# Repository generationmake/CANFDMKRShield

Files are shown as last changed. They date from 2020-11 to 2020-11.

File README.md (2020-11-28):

# CANFDMKRShield
Shield with CAN FD Controller MCP2517 for Arduino MKR

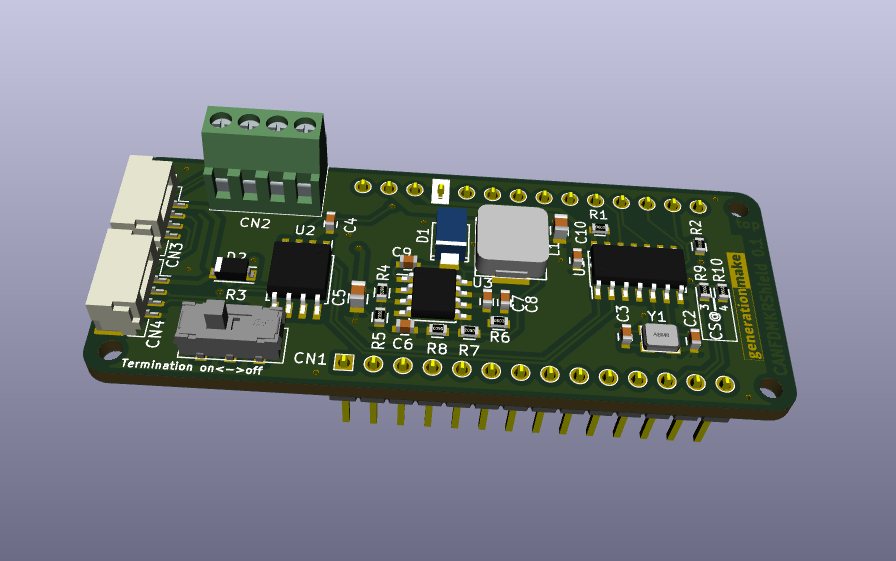
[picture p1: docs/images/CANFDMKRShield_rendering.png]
CANFDMKRShield rendering


## pin usage

### Arduino MKR connector CN1

| **Pin** | **Pin Name** | **Signal** | **Description** |
|:---:|:---:|:---:|:---:|
| 1 | AREF | | |
| 2 | DAC0/A0 | | |
| 3 | A1 | | |
| 4 | A2 | | |
| 5 | A3 | | |
| 6 | A4 | | |
| 7 | A5 | | |
| 8 | A6 | | |
| 9 | 0 | | |
| 10 | 1 | | |
| 11 | 2 | | |
| 12 | 3 | MCP2517_CS1 | option 1 for chip select for MCP2517 |
| 13 | 4 | MCP2517_CS2 | option 2 for chip select for MCP2517 |
| 14 | 5 | | |
| 15 | 6 | | |
| 16 | 7 | MCP2517_INT | interrupt from MCP2517 |
| 17 | 8/MOSI | SPI_MOSI | SPI to MCP2517 |
| 18 | 9/SCK | SPI_SCK | SPI to MCP2517 |
| 19 | 10/MISO | SPI_MISO | SPI to MCP2517 |
| 20 | 11/SDA | | |
| 21 | 12/SCL | | |
| 22 | 13/RX | | |
| 23 | 14/TX | | |
| 24 | RESET | | |
| 25 | GND | GND | |
| 26 | VCC | 3V3-rail | supply voltage for board |
| 27 | VIN | +5V | 5V supply output from CAN connector  |
| 28 | 5V0 | | |

### CAN connector CN2

compatible to Sparkfun Qwiic. JST SH 1mm 4-pin.

| **Pin** | **Signal** | **Description** |
|:---:|:---:|:---:|
| 1 | GND | |
| 2 | CAN_L | |
| 3 | CAN_H | |
| 4 | VCC | input to Arduino, up to 24 V |

### UAVCAN dronecode connector CN3 and CN4

compatible to UAVCAN dronecode. JST GH 1.25mm 4-pin.

| **Pin** | **Signal** | **Description** |
|:---:|:---:|:---:|
| 1 | CANVCC | up to 5.5 V |
| 2 | CAN_H | |
| 3 | CAN_L | |
| 4 | GND | |

CANVCC can be connected to Arduino via diode D2 as desribed in the dronecode spec. The direction of the diode defines wether current is sourced from the connector or supplied into the UAVCAN system. If no connection is desired just leave D2 unpopulated.

## PCB

### Top

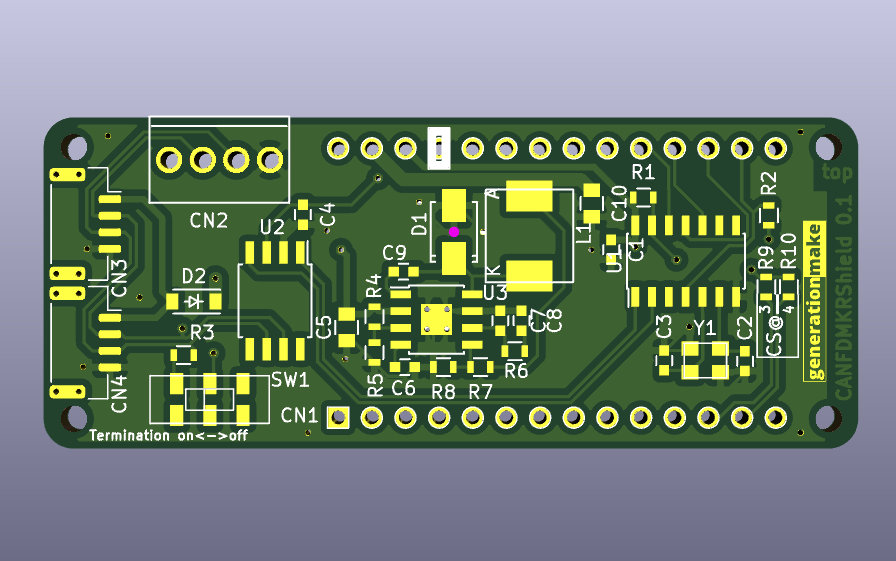
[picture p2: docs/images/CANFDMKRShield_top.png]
CANFDMKRShield PCB top


### Bottom

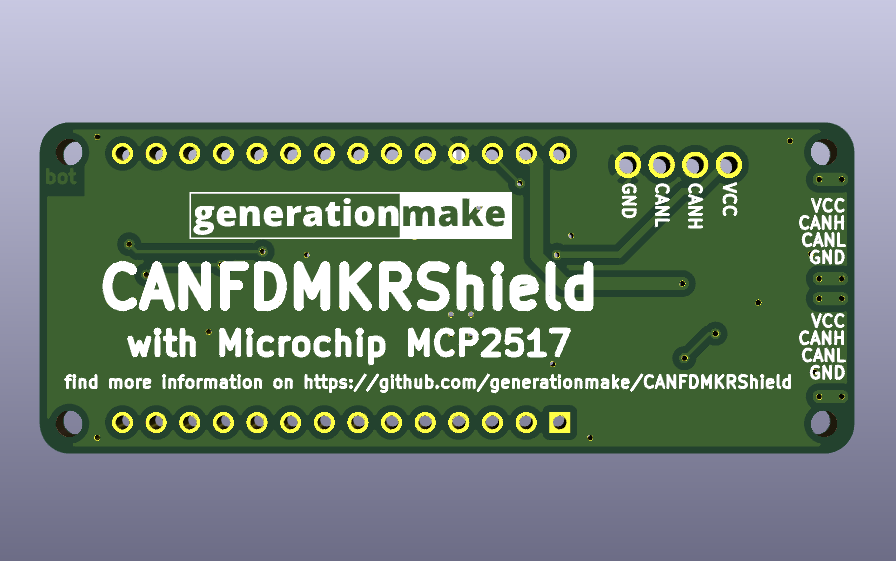
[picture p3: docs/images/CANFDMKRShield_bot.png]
CANFDMKRShield PCB bot


## Resources

### Datasheets

 * http://ww1.microchip.com/downloads/en/DeviceDoc/MCP2517FD-External-CAN-FD-Controller-with-SPI-Interface-20005688B.pdf
 
### Arduino Libraries

 * tbd

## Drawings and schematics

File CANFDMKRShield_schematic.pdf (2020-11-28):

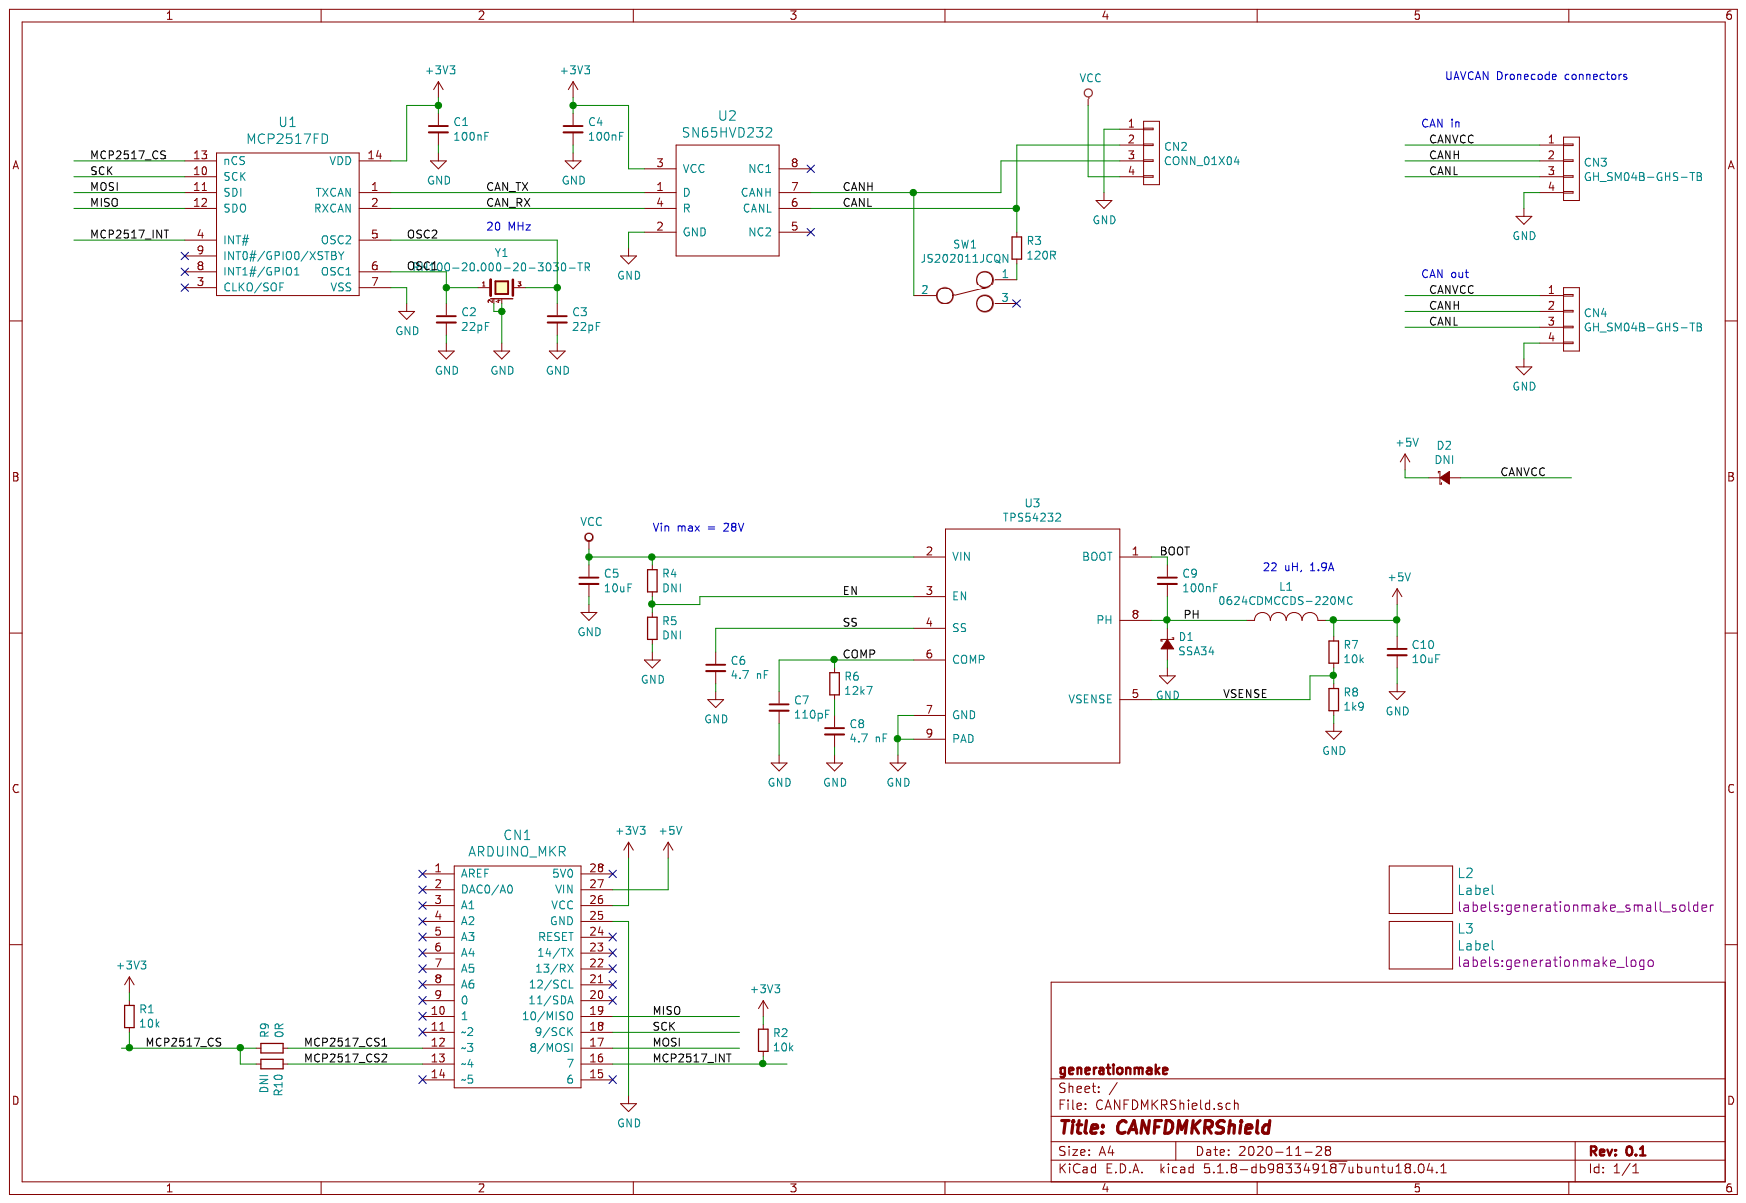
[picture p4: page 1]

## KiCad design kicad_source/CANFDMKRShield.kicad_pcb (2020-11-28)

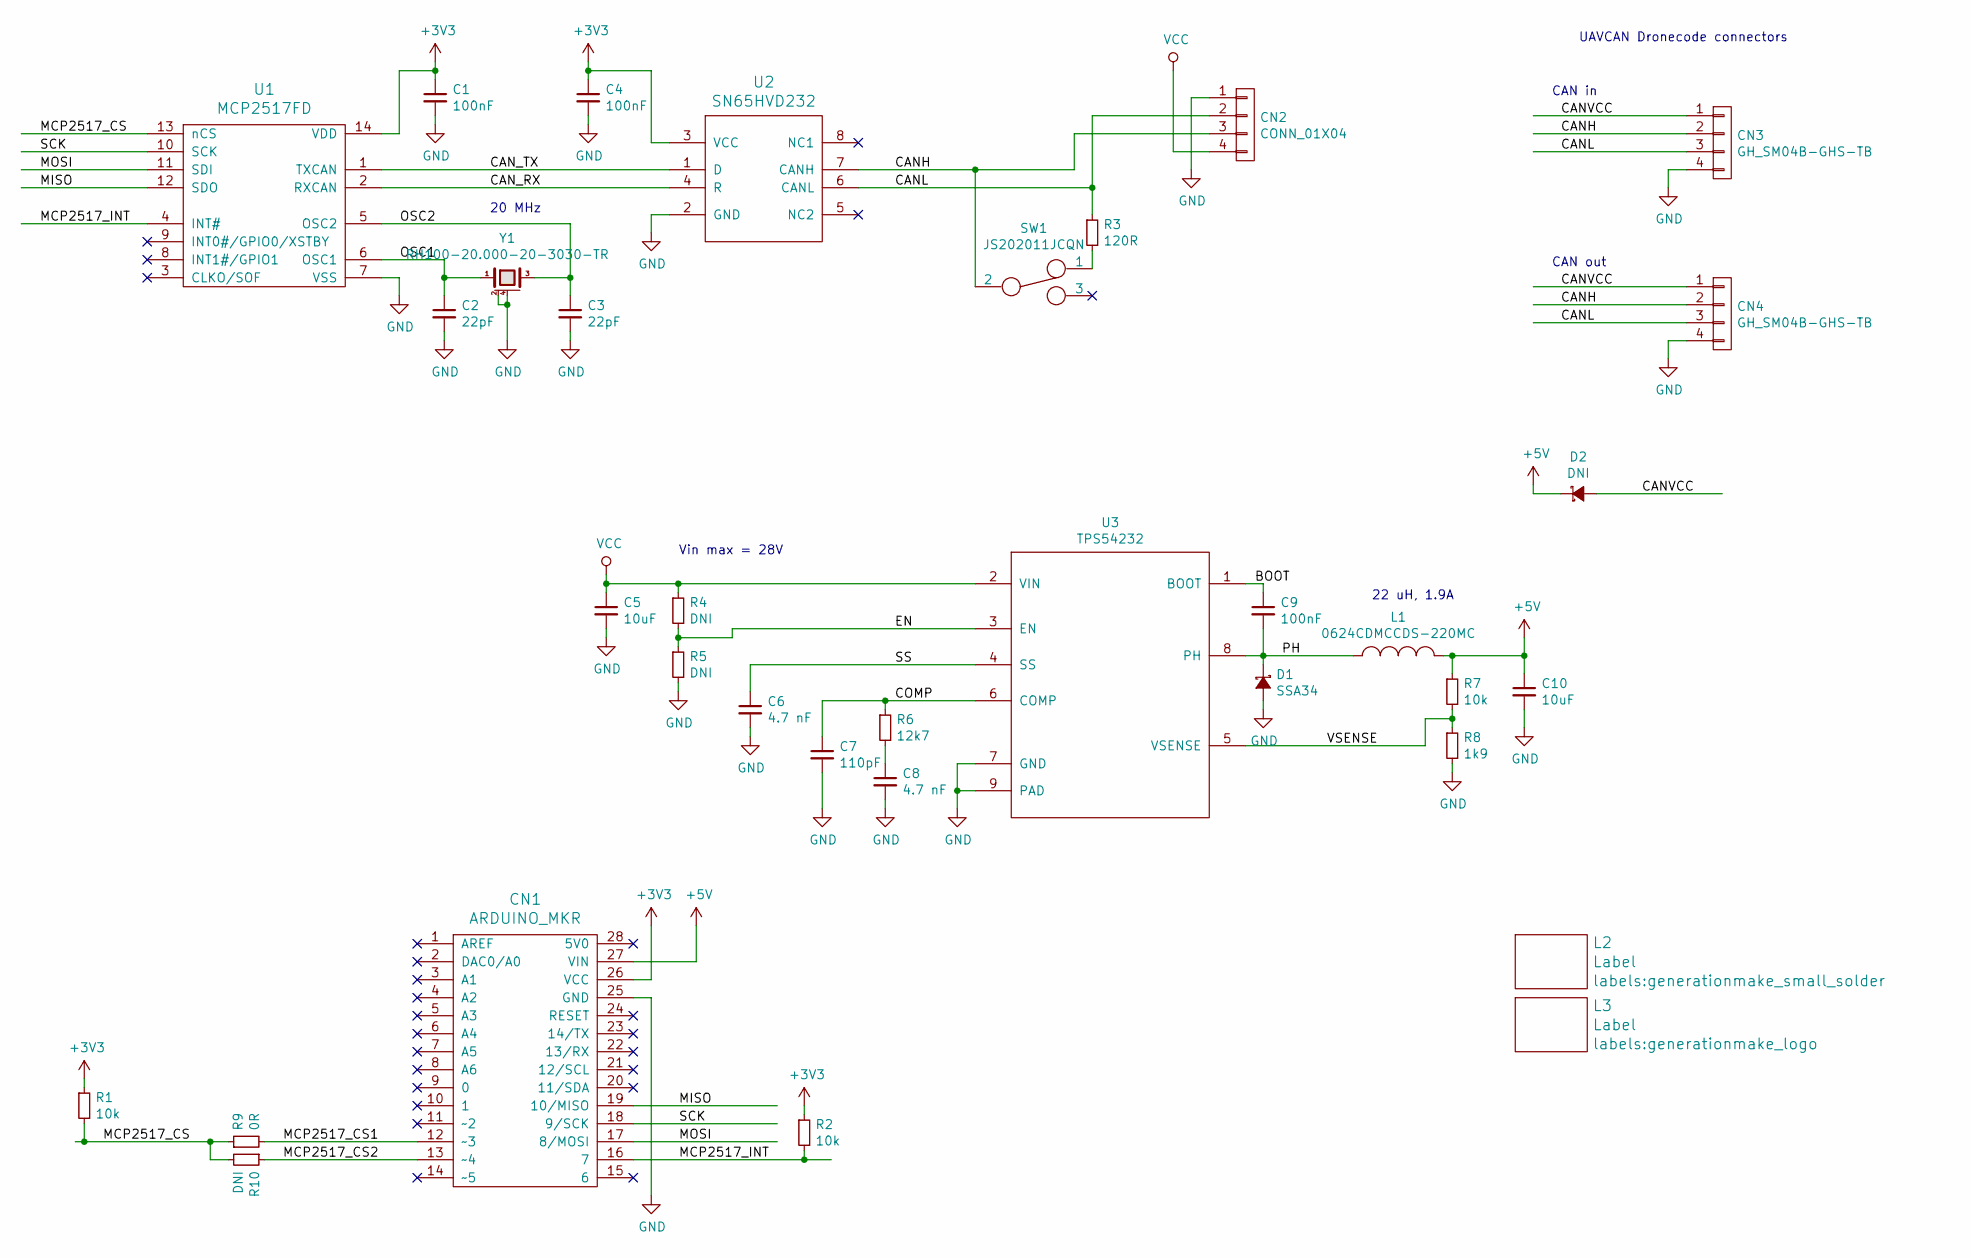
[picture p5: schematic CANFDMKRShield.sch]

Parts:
C1, C4, C9: 100nF; C_0603
C2, C3: 22pF; C_0603
C5, C10: 10uF; C_0805
C6, C8: 4.7 nF; C_0603
C7: 110pF; C_0603
CN1: ARDUINO_MKR; ARDUINO_MKR_HOLES_PINHEADER_EDGE
CN2: CONN_01X04; WR-TBL_691210910004
CN3, CN4: GH_SM04B-GHS-TB; JST_GH_SM04B-GHS-TB_1x04-1MP_P1.25mm_Horizontal
D1: SSA34; SMA_Standard
D2: DNI; SOD-123
L1: 0624CDMCCDS-220MC; Sumida-0624CDMCCDS
L2: Label; generationmake_small_solder
L3: Label; generationmake_logo
R1, R2, R7: 10k; R_0603
R3: 120R; R_0603
R4, R5, R10: DNI; R_0603
R6: 12k7; R_0603
R8: 1k9; R_0603
R9: 0R; R_0603
SW1: JS202011JCQN; CK_JS202011JCQN
U1: MCP2517FD; SOIC-14_3.9x8.7mm_Pitch1.27mm
U2: SN65HVD232; SOIJ-8_5.3x5.3mm_Pitch1.27mm
U3: TPS54232; SOIC-8-1EP_3.9x4.9mm_Pitch1.27mm
Y1: RH100-20.000-20-3030-TR; Crystal_SMD_3.2x2.5mm_4Pad

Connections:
+3V3: C1.1, C4.1, CN1.26 (VCC), R1.1, R2.1, U1.14 (VDD), U2.3 (VCC)
+5V: C10.1, CN1.27 (VIN), D2.1 (K), L1.2, R7.1
/BOOT: C9.1, U3.1 (BOOT)
/CANH: CN2.3, CN3.2, CN4.2, SW1.2, U2.7 (CANH)
/CANL: CN2.2, CN3.3, CN4.3, R3.1, U2.6 (CANL)
/CANVCC: CN3.1, CN4.1, D2.2 (A)
/CAN_RX: U1.2 (RXCAN), U2.4 (R)
/CAN_TX: U1.1 (TXCAN), U2.1 (D)
/COMP: C7.1, R6.1, U3.6 (COMP)
/EN: R4.2, R5.1, U3.3 (EN)
/MCP2517_CS: R1.2, R9.1, R10.2, U1.13 (nCS)
/MCP2517_CS1: CN1.12 (~~3), R9.2
/MCP2517_CS2: CN1.13 (~~4), R10.1
/MCP2517_INT: CN1.16 (7), R2.2, U1.4 (INT#)
/MISO: CN1.19 (10/MISO), U1.12 (SDO)
/MOSI: CN1.17 (8/MOSI), U1.11 (SDI)
/OSC1: C2.1, U1.6 (OSC1), Y1.1
/OSC2: C3.1, U1.5 (OSC2), Y1.3
/PH: C9.2, D1.1 (K), L1.1, U3.8 (PH)
/SCK: CN1.18 (9/SCK), U1.10 (SCK)
/SS: C6.1, U3.4 (SS)
/VSENSE: R7.2, R8.1, U3.5 (VSENSE)
GND: C1.2, C2.2, C3.2, C4.2, C5.2, C6.2, C7.2, C8.2, C10.2, CN1.25 (GND), CN2.1, CN3.4, CN4.4, D1.2 (A), R5.2, R8.2, U1.7 (VSS), U2.2 (GND), U3.7 (GND), U3.9 (PAD), Y1.2 (case), Y1.4 (case)
unnamed: C8.1, R6.2
unnamed: R3.2, SW1.1
VCC: C5.1, CN2.4, R4.1, U3.2 (VIN)

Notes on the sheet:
22 uH, 1.9A
Vin max = 28V
CAN in
UAVCAN Dronecode connectors
CAN out
20 MHz

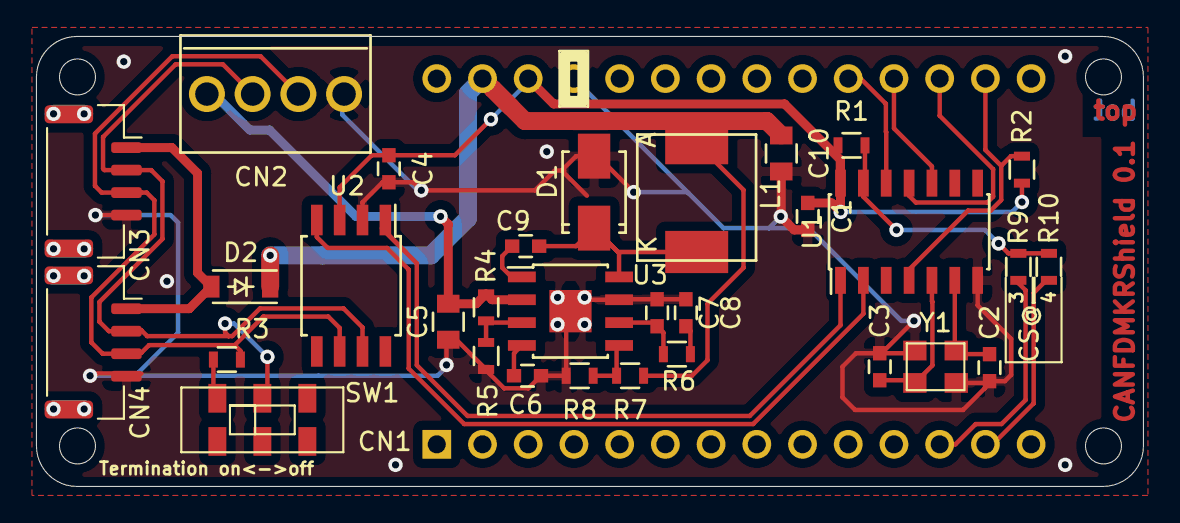
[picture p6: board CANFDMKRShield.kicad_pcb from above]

Board: 2 copper layers, 61.5 x 25.0 mm, 34 parts (1 on the bottom side), 26 nets.

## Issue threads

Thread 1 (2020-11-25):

Provide Dronecode Autopilot Connector Standard connectors

aentinger, 2020-11-25:
The Zubax Orel 20 ESCs and many UAVCAN enabled sensor/actuators utilize the [JST GH](http://www.jst-mfg.com/product/detail_e.php?series=105) connectors with a pitch of 1.25 mm.

**Zubax Orel 20 Pinout**

| **Pin** | **Signal** |
|:-------:|:----------:|
| 1       | VCC        |
| 2       | CAN_H      |
| 3       | CAN_L      |
| 4       | GND        |

Providing 2 such connectors (CAN-IN, CAN-OUT) would allow easy interfacing with other UAVCAN enabled products.

However, there are a couple of open questions on my end and I'm hoping @pavel-kirienko can provide some clarity here. Internet documentation on the **Dronecode Autopilot Connector Standard** is both scarce and contradictory. It seems that the proposed standard has 6 pins, but I'm not sure on the exact pin-out. The Zubax Orel 20 ESCs have a 4-Pin connector. Why this discrepancy? What kind of pinout can we expect to be more widely adopted in the future?

pavel-kirienko, 2020-11-25:
Per the Dronecode Autopilot Connector Standard, the CAN connector has 4
pins as you wrote. This is also confirmed in the recently published DS-015
standard. 6-pin CAN connectors have never been defined by Dronecode.

On Wed, Nov 25, 2020, 09:48 Alexander Entinger <notifications@github.com>
wrote:

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

generationmake, 2020-11-25:
Hi @pavel-kirienko and @aentinger
Thank you for your input. I will add Dronecode CAN connectors. The spec is well defined and I think I know what to do.

aentinger, 2020-11-25:
It was this [post](https://www.dronetrest.com/t/dronecode-cables-and-connectors/1661), that got me confused. Plus a lot of dead links that come up at the very top when googling, e.g. [Link](https://wiki.dronecode.org/workgroup/connectors/start), [Link](https://pixhawk.org/pixhawk-connector-standard), [Link](https://www.dronecode.org/hardware/).

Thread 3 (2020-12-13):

support MCP2518FD

generationmake, 2020-12-13:
The MCP2517FD is not recommended for new designs. Replacement is MCP2518FD and should be pin compatible and is better available and cheaper.
https://ww1.microchip.com/downloads/en/DeviceDoc/External-CAN-FD-Controller-with-SPI-Interface-DS20006027B.pdf

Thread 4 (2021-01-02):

add fuse on CANVCC

generationmake, 2021-01-02:
dronecode standard recommends placing a fuse on CANVCC.
Install a polyfuse.
use Bel Fuse 0ZCM0020FF2G 0603
digikey 507-1821-1-ND
https://www.digikey.de/product-detail/de/bel-fuse-inc/0ZCM0020FF2G/507-1821-1-ND/4156270

see https://github.com/generationmake/CANFDZeroHAT/issues/2

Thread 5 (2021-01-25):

use correct footprint for CAN transceiver

generationmake, 2021-01-25:
footprint is a little bit to big

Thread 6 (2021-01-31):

add protection for CAN

generationmake, 2021-01-31:
add some EMI/ESD protection devices for the CAN bus.

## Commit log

2020-11-15 added kicad project with schematic
    [CANFDMKRShield.kicad_pcb, CANFDMKRShield.sch]
2020-11-15 started layout
    [CANFDMKRShield.kicad_pcb, CANFDMKRShield.sch]
2020-11-15 added schematic pdf and image
2020-11-19 added voltage regulators, updated images and pdf schematic
    [CANFDMKRShield.kicad_pcb, CANFDMKRShield.sch]
2020-11-25 added dronecode CAN connectors, updated images and schematic pdf
    [CANFDMKRShield.kicad_pcb, CANFDMKRShield.sch]
2020-11-26 updated board shape, changed switch type
    [CANFDMKRShield.kicad_pcb, CANFDMKRShield.sch]
2020-11-27 added diode D2 to connect CAN VCC to 5V
    [CANFDMKRShield.kicad_pcb, CANFDMKRShield.sch]
2020-11-27 added option to use different CS line for SPI
    [CANFDMKRShield.kicad_pcb, CANFDMKRShield.sch]
2020-11-28 defined type of crystal, updated 3d models of footprints
    [CANFDMKRShield.kicad_pcb, CANFDMKRShield.sch]
2020-11-28 updated layout
    [CANFDMKRShield.kicad_pcb]
2020-11-28 added some labels, updated images and schematic pdf
    [CANFDMKRShield.kicad_pcb, CANFDMKRShield.sch]
